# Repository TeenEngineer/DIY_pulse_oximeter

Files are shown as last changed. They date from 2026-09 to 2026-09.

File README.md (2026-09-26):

# DIY_pulse_oximeter
Hello! I made this project just as a way to make medical equipment with cheaper components(while retaining quality of the measurements)

# Description
The device uses MAX30102 to measure pulse and SpO2, and the microcontroller is Atmega328p(like the one on arduino nano). I am planning to use a 64x32 0.49" OLED screen to display info, and I also integrated a MCP73831 charging circuit for the battery(planning to use 250mAh tiny li-po), and CH340C for quickly writing firmware. It also used DW01A for over-discharge protection, with FS8205A responsible for cutting off power. And finally, AP2112K-3.3TRG1 supplies 3.3V stable current from the battery.

About assembling the PCB, I am going to order from Aivon(cuz JLCPCB doesn't offer PCBA in my country)

# Schematic, PCB
You can view the schematic and PCB layout **[here](https://kicanvas.org/?repo=https://github.com/TeenEngineer/DIY_pulse_oximeter)**
**OR**
Here is a schematic


# PCB
This is the current layout(in 3D):




# BOM
|Name |Price |
|---|---|
|Bare PCBs 5pcs |5$ |
|PCB Assembly for 5pcs |36$ |
|Shipping(Fedex, the only cheap option) |0$(First order discount)|
|0.49" 64x32 OLED screen(https://ali.click/3mfuk1f, including shipping)|2.68$ |
|Total |44$(in case price of oled goes up |

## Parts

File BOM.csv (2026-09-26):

Reference | Qty | Value | DNP | Exclude from BOM | Exclude from Board | Footprint | Datasheet | MPN
C1,C2 | 2 | 22pF |  |  |  | Capacitor_SMD:C_0603_1608Metric | ~ | CL10A475KQ8NNNC
C3,C4,C5,C6,C7,C11 | 6 | 100nF |  |  |  | Capacitor_SMD:C_0603_1608Metric | ~ | CL10B104KB8NNNC
C8 | 1 | 1uF |  |  |  | Capacitor_SMD:C_0603_1608Metric | ~ | C0603C105K9RACAUTO
C9,C10 | 2 | 4.7uF |  |  |  | Capacitor_SMD:C_0603_1608Metric | ~ | CL10A475KQ8NNNC
D1 | 1 | LED |  |  |  | LED_SMD:LED_0805_2012Metric | ~ | CMD17-21VRD/TR8
J1 | 1 | USB_C_Receptacle_USB2.0_14P |  |  |  | Connector_USB:USB_C_Receptacle_HRO_TYPE-C-31-M-12 | https://www.usb.org/sites/default/files/documents/usb_type-c.zip | 12402012E212A
J2 | 1 | Conn_01x04_Socket |  |  |  | Connector_PinSocket_2.54mm:PinSocket_1x04_P2.54mm_Vertical | ~
J3 | 1 | Conn_01x02_Socket |  |  |  | Connector_JST:JST_PH_S2B-PH-K_1x02_P2.00mm_Horizontal | ~
Q1 | 1 | FS8205A |  |  |  | fs8205:SOT-23-6L_TCP | FS8205A | FS8205A
R1,R2 | 2 | 5.1k ohm |  |  |  | Resistor_SMD:R_0603_1608Metric | ~ | FRC0603F5101TS
R3,R4 | 2 | 10k ohm |  |  |  | Resistor_SMD:R_0603_1608Metric | ~ | RC0603FR-0710KL
R5 | 1 | 470ohm |  |  |  | Resistor_SMD:R_0603_1608Metric | ~ | 0603WAF4700T5E
R6,R10 | 2 | 1k ohm |  |  |  | Resistor_SMD:R_0603_1608Metric | ~ | FRC0603F1001TS,FRC0603F1001TS
R7 | 1 | 100 ohm |  |  |  | Resistor_SMD:R_0603_1608Metric | ~ | Y4021100R000B9W
R8,R9 | 2 | 4.7k ohm |  |  |  | Resistor_SMD:R_0603_1608Metric | ~ | RC0603FR-074K7L
R11 | 1 | 2k ohm |  |  |  | Resistor_SMD:R_0603_1608Metric | ~ | 0603WAF2001T5E
SW1 | 1 | SW_Push |  |  |  | Button_Switch_SMD:SW_Push_1P1T_NO_CK_KMR2 | ~ | KMR641NG ULC LFS
SW2 | 1 | RESET |  |  |  | Button_Switch_SMD:SW_Push_1P1T_NO_CK_KMR2 | ~ | KMR641NG ULC LFS
U1 | 1 | ATMEGA328P-AU |  |  |  | ATMEGA328P-AU:QFP80P900X900X120-32N |  | ATMEGA328P-AU
U2 | 1 | AP2112K-3.3TRG1 |  |  |  | ap2112k:SOT_RG1_DIO | AP2112K-3.3TRG1 | AP2112K-3.3TRG1
U3 | 1 | DW01A |  |  |  | Package_TO_SOT_SMD:SOT-23-6 | https://hmsemi.com/downfile/DW01A.PDF | DW01A
U4 | 1 | MAX30102EFD_ |  |  |  | MAX30102EFD_:PSON80P330X560X165-14N |  | MAX30102EFD+
U5 | 1 | MCP73831-2-OT |  |  |  | Package_TO_SOT_SMD:SOT-23-5 | http://ww1.microchip.com/downloads/en/DeviceDoc/20001984g.pdf | MCP73831T-2ACI/OT
U6 | 1 | CH340C |  |  |  | CH340C:SOIC127P600X180-16N | https://datasheet.lcsc.com/szlcsc/Jiangsu-Qin-Heng-CH340C_C84681.pdf | CH340C
Y1 | 1 | 8MHz |  |  |  | Crystal:Crystal_SMD_3225-4Pin_3.2x2.5mm | ~ | X32258MOB4SI

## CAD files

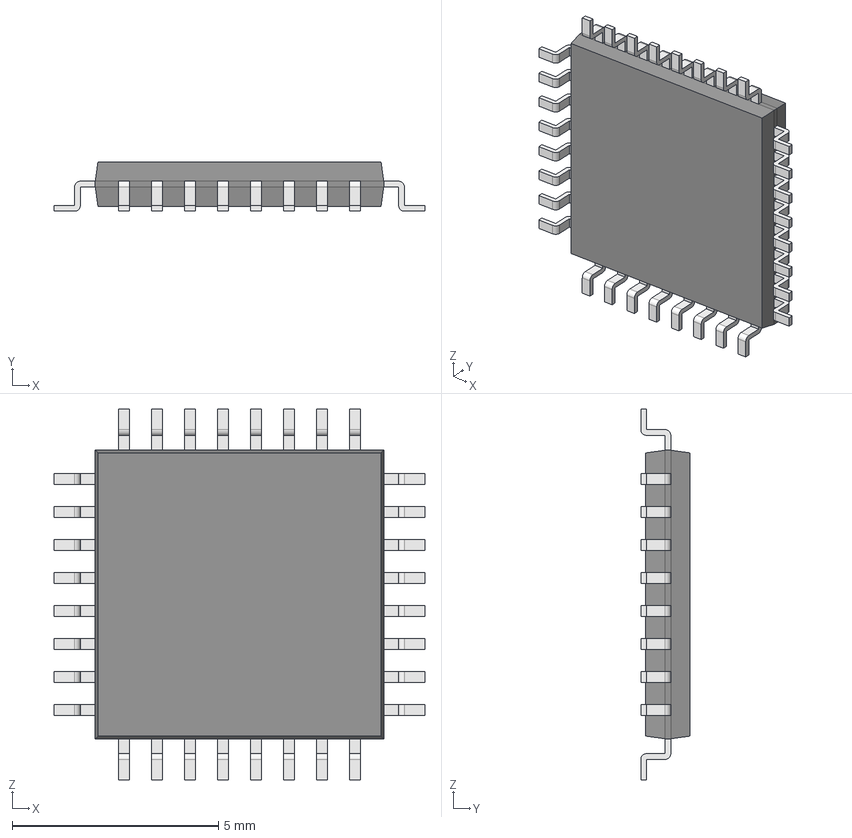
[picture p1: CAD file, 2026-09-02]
PCB/ATMEGA328P-AU/ATMEGA328P-AU.step
9.00 x 1.20 x 9.00 mm
Body001 (Mirror #1) x 8
Body002 (Mirror #2) x 8
XY-plane x 15
X-axis x 15

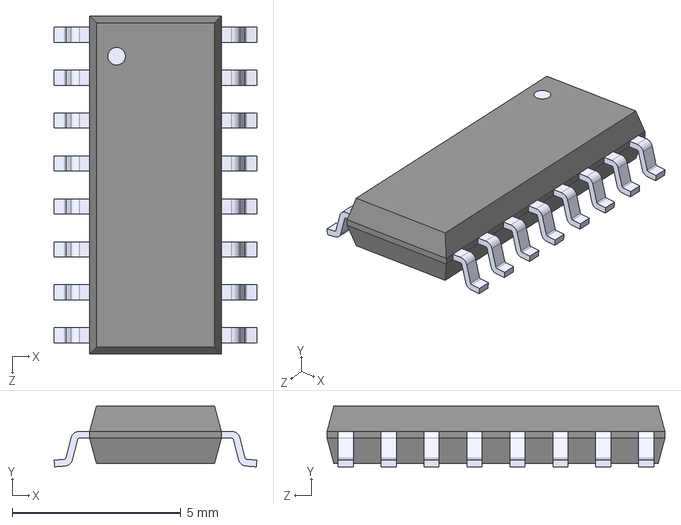
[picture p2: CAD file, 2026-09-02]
PCB/CH340C/CH340C.step
6.00 x 1.80 x 10.0 mm

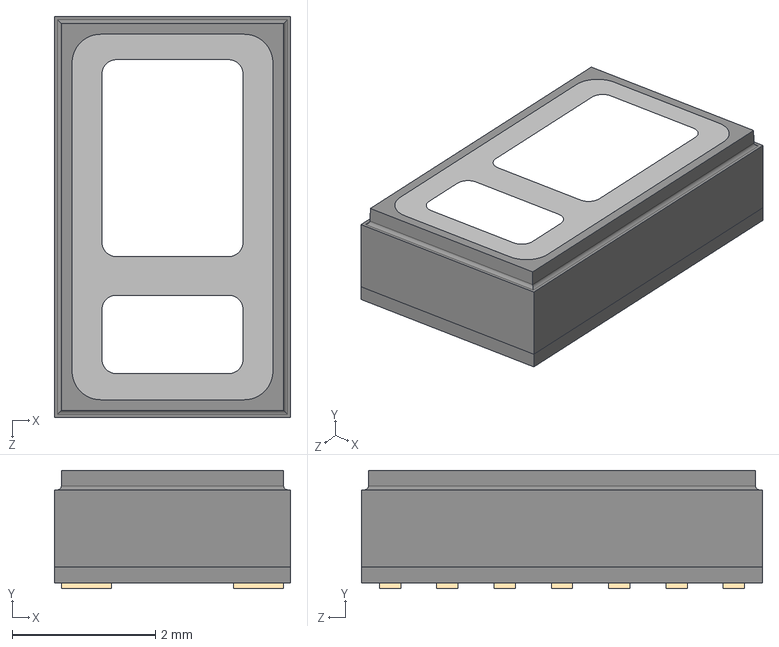
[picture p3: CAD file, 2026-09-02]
PCB/MAX30102EFD_/MAX30102EFD_.step
3.30 x 1.65 x 5.60 mm

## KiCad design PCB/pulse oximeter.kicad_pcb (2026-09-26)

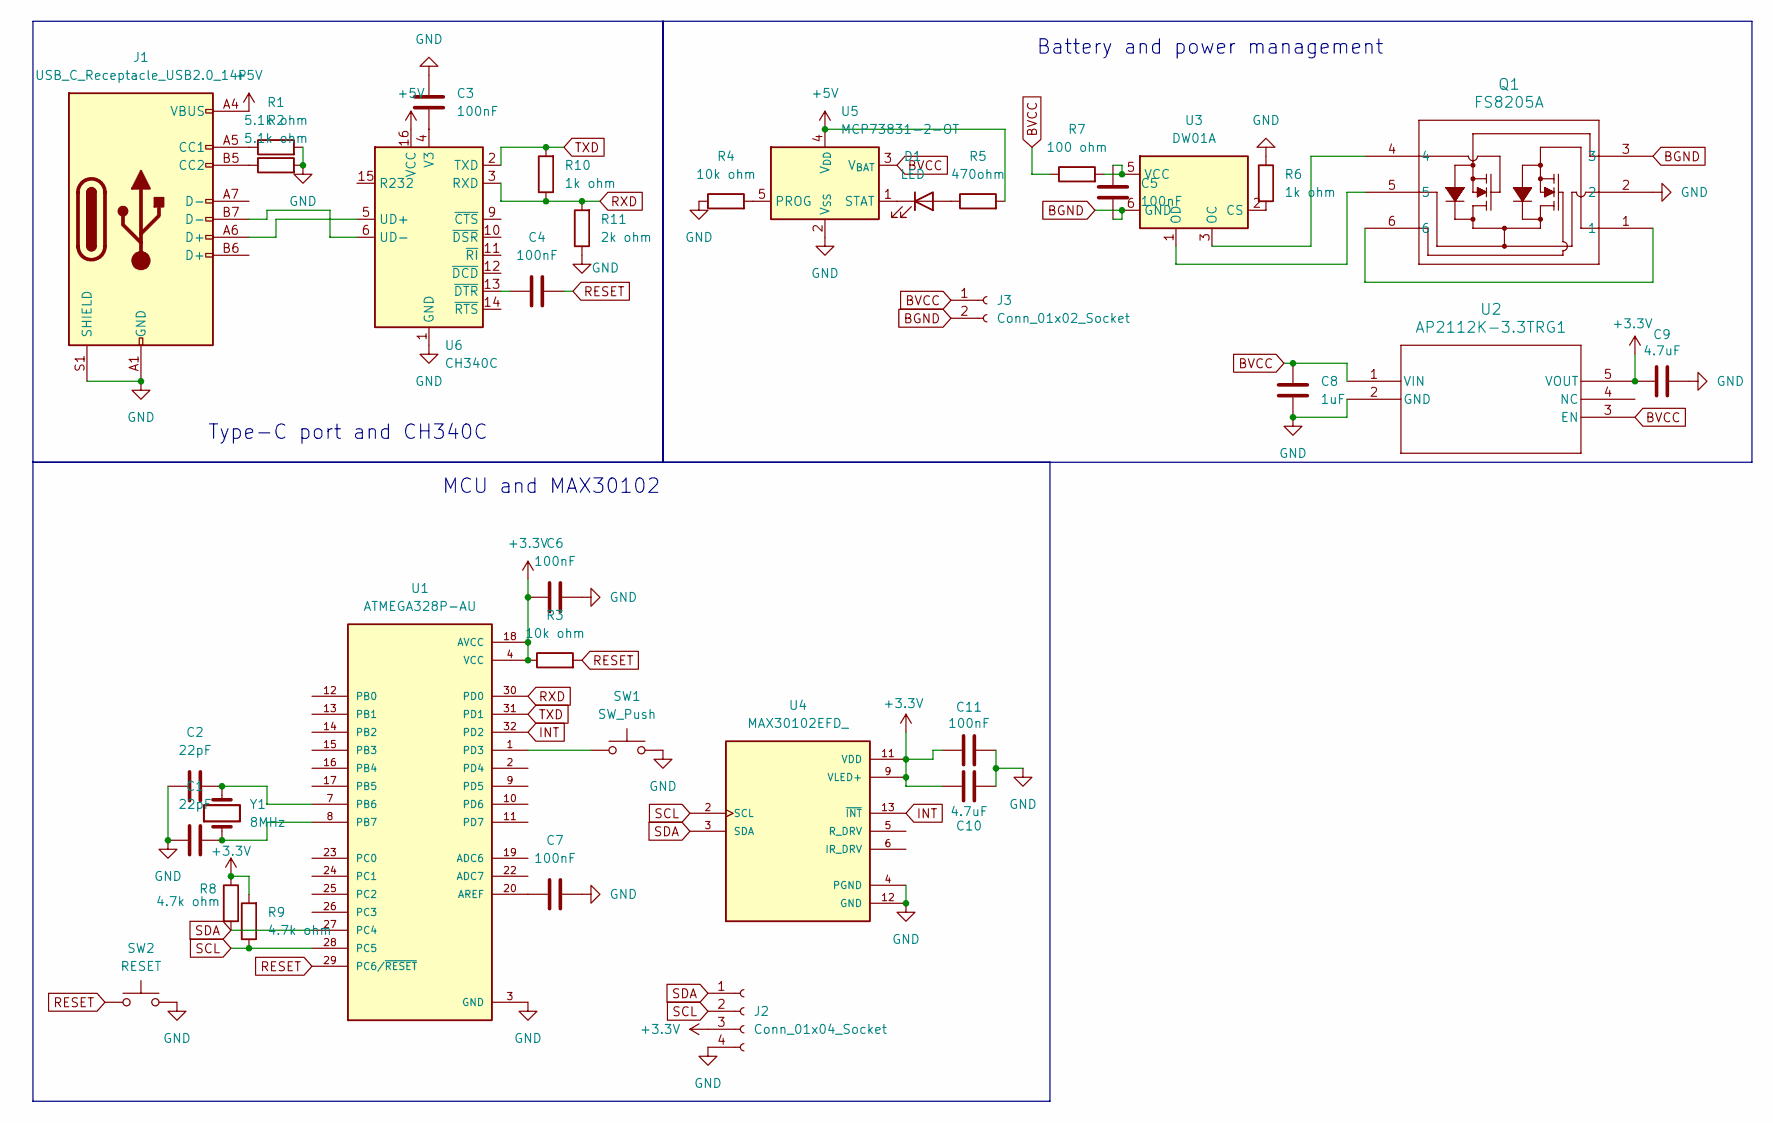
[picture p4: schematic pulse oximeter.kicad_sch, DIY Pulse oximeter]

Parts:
C1, C2: 22pF; C_0603_1608Metric; MPN CL10A475KQ8NNNC
C3, C4, C5, C6, C7, C11: 100nF; C_0603_1608Metric; MPN CL10B104KB8NNNC
C8: 1uF; C_0603_1608Metric; MPN C0603C105K9RACAUTO
C9, C10: 4.7uF; C_0603_1608Metric; MPN CL10A475KQ8NNNC
D1: LED; LED_0805_2012Metric; MPN CMD17-21VRD/TR8
J1: USB_C_Receptacle_USB2.0_14P; USB_C_Receptacle_HRO_TYPE-C-31-M-12; MPN 12402012E212A
J2: Conn_01x04_Socket; PinSocket_1x04_P2.54mm_Vertical
J3: Conn_01x02_Socket; JST_PH_S2B-PH-K_1x02_P2.00mm_Horizontal
Q1: FS8205A; SOT-23-6L_TCP; MPN FS8205A
R1, R2: 5.1k ohm; R_0603_1608Metric; MPN FRC0603F5101TS
R3, R4: 10k ohm; R_0603_1608Metric; MPN RC0603FR-0710KL
R5: 470ohm; R_0603_1608Metric; MPN 0603WAF4700T5E
R6, R10: 1k ohm; R_0603_1608Metric; MPN FRC0603F1001TS
R7: 100 ohm; R_0603_1608Metric; MPN Y4021100R000B9W
R8, R9: 4.7k ohm; R_0603_1608Metric; MPN RC0603FR-074K7L
R11: 2k ohm; R_0603_1608Metric; MPN 0603WAF2001T5E
SW1: SW_Push; SW_Push_1P1T_NO_CK_KMR2; MPN KMR641NG ULC LFS
SW2: RESET; SW_Push_1P1T_NO_CK_KMR2; MPN KMR641NG ULC LFS
U1: ATMEGA328P-AU; QFP80P900X900X120-32N; PARTREV 8271A
U2: AP2112K-3.3TRG1; SOT_RG1_DIO; MPN AP2112K-3.3TRG1
U3: DW01A; SOT-23-6; MPN DW01A
U4: MAX30102EFD_; PSON80P330X560X165-14N; PARTREV 0
U5: MCP73831-2-OT; SOT-23-5; MPN MCP73831T-2ACI/OT
U6: CH340C; SOIC127P600X180-16N; MPN CH340C
Y1: 8MHz; Crystal_SMD_3225-4Pin_3.2x2.5mm; MPN X32258MOB4SI

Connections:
+3.3V: C6.1, C9.1, C10.1, C11.1, J2.3, R3.1, R8.1, R9.2, U1.4 (VCC), U1.6 (VCC), U1.18 (AVCC), U2.5 (VOUT), U4.9 (VLED+), U4.10 (VLED+), U4.11 (VDD)
+5V: J1.A4 (VBUS), J1.A9 (VBUS), J1.B4 (VBUS), J1.B9 (VBUS), R5.2, U5.4 (V_{DD}), U6.16 (VCC)
BGND: C5.2, J3.2, Q1.3, U3.6 (GND)
BVCC: C8.1, J3.1, R7.1, U2.1 (VIN), U2.3 (EN), U5.3 (V_{BAT})
GND: C1.1, C2.1, C3.1, C6.2, C7.2, C8.2, C9.2, C10.2, C11.2, J1.A1 (GND), J1.A12 (GND), J1.B1 (GND), J1.B12 (GND), J1.S1 (SHIELD), J2.4, Q1.2, R1.2, R2.2, R4.1, R6.1, R11.1, SW1.2, SW2.2, U1.3 (GND), U1.5 (GND), U1.21 (GND), U2.2 (GND), U4.4 (PGND), U4.12 (GND), U5.2 (V_{SS}), U6.1 (GND)
INT: U1.32 (PD2), U4.13 (~INT)
unnamed: D1.2 (A), R5.1
unnamed: D1.1 (K), U5.1 (STAT)
unnamed: J1.A5 (CC1), R1.1
unnamed: J1.B5 (CC2), R2.1
unnamed: Q1.1, Q1.6
unnamed: C7.1, U1.20 (AREF)
unnamed: C2.2, U1.7 (PB6), Y1.2
unnamed: C1.2, U1.8 (PB7), Y1.1
unnamed: SW1.1, U1.1 (PD3)
unnamed: R6.2, U3.2 (CS)
unnamed: Q1.4, U3.3 (OC)
unnamed: Q1.5, U3.1 (OD)
unnamed: C5.1, R7.2, U3.5 (VCC)
unnamed: R4.2, U5.5 (PROG)
unnamed: J1.A6 (D+), U6.5 (UD+)
unnamed: J1.B7 (D-), U6.6 (UD-)
unnamed: C3.2, U6.4 (V3)
unnamed: C4.2, U6.13 (~DTR)
RESET: C4.1, R3.2, SW2.1, U1.29 (PC6/~RESET)
RXD: R10.1, R11.2, U1.30 (PD0), U6.3 (RXD)
SCL: J2.2, R9.1, U1.28 (PC5), U4.2 (SCL)
SDA: J2.1, R8.2, U1.27 (PC4), U4.3 (SDA)
TXD: R10.2, U1.31 (PD1), U6.2 (TXD)

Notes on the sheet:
Battery and power management
MCU and MAX30102
Type-C port and CH340C

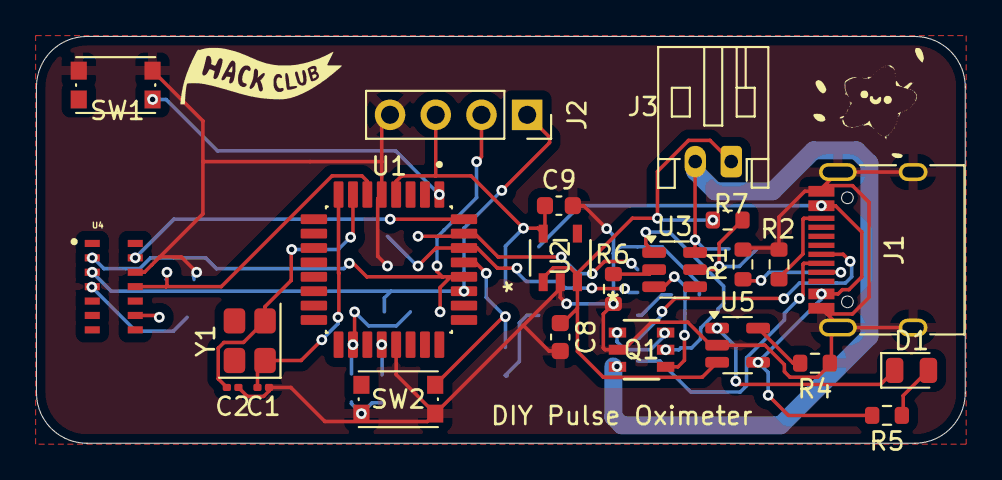
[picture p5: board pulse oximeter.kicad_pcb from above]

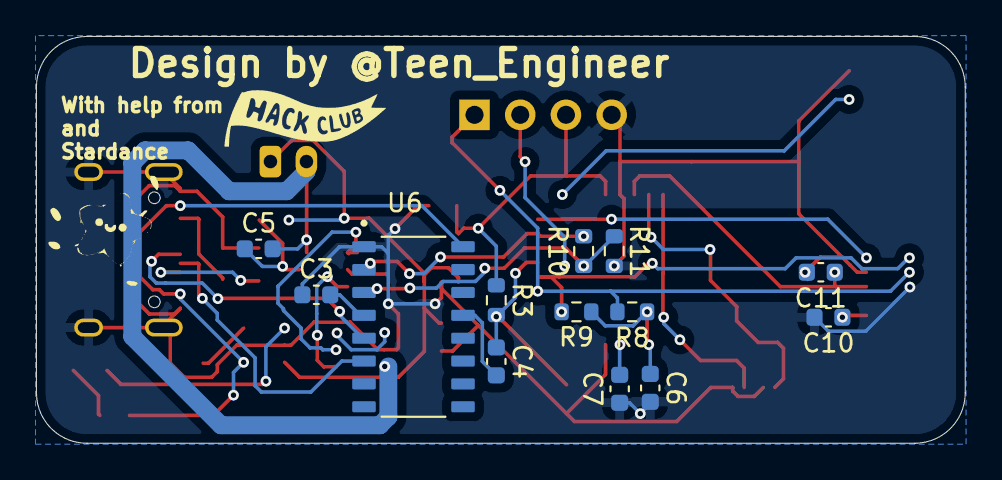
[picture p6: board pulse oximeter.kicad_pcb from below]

Board: 2 copper layers, 51.6 x 22.6 mm, 40 parts (15 on the bottom side), 29 nets.

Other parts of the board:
., .#2: LOGO
 : LOGO
 #2: LOGO

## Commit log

2026-09-01 Update README with project details and BOM
    Added project description, PCB layout images, and BOM details.
2026-09-02 Update pulse oximeter.kicad_sch
    [pulse oximeter.kicad_sch]
2026-09-03 Update BOM.csv with new item and total price
    [BOM.csv]
2026-09-03 Fix formatting in BOM.csv and update total
    [BOM.csv]
2026-09-04 Update pulse oximeter.kicad_pcb
    [pulse oximeter.kicad_pcb]
2026-09-06 Edit PCB and Schematic
    [pulse oximeter.kicad_pcb, pulse oximeter.kicad_sch]
2026-09-26 Organized files
    [ATMEGA328P-AU.step, BOM.csv, CH340C.step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]
2026-10-31 Add main BOM
